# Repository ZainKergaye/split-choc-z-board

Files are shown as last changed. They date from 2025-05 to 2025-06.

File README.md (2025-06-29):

# Choc split-key z-board

The choc split key zboard is another ergonomic split-keyboard designed for comfort and efficiency. Using wired USB-C connectors to communicate between halves, it is a plain simple keyboard.

## Table of Contents

1. [Introduction](#introduction)
2. [Features](#features)
3. [Getting Started](#getting-started)
4. [Hardware](#hardware)
5. [Initial Board Testing](#initial-board-testing)
6. [Assembly](#assembly)
7. [Firmware Installation](#firmware-installation)
8. [Troubleshooting](#troubleshooting)

## Features

- Ergonomic split design for improved comfort
- Custom PCB with SMD and THC components
- Open-source firmware using [QMK](https://docs.qmk.fm).
- 3D printed [case](https://www.printables.com/@ZainKergaye_241410)

## Getting Started

To make your own keyboard order all the parts in the [hardware](#hardware) section. Solder
everything according to the silkscreen, be prepared to solder SMD and THC components. 3D
print the case. Build and flash the firmware. Then you are done!

## Hardware

### PCB

Order the PCB from any manufacurer you want, the exported gerbers are below.

[Left half gerbers](./split-choc-z-board/gerbers/left-half-gerbers.zip)

### Components

[Choc v1 switches](https://www.amazon.com/dp/B0BLC9BKW8)

[Keycaps](https://www.amazon.com/dp/B0D2DCDBSW)

[QSPI Flash](https://www.digikey.com/en/products/detail/winbond-electronics/W25Q128JVSIQ-TR/5803944)

[RP2040](https://www.digikey.com/en/products/detail/raspberry-pi/SC0914-13/14306010?s=N4IgTCBcDaIE4AcwAYAsyQF0C%2BQ)

[Button](https://www.digikey.com/en/products/detail/e-switch/TL3315NF250Q/1870396)

[Resistor 10k](https://www.digikey.com/en/products/detail/bourns-inc/CR0603-FX-1002ELF/3593188)

[Resistor 27.4k](https://www.digikey.com/en/products/detail/bourns-inc/CR0603-FX-27R4ELF/3783905)

[Resistor 4.99k](https://www.digikey.com/en/products/detail/bourns-inc/CR0603-FX-4991ELF/2345092)

[Resistor 1k](https://www.digikey.com/en/products/detail/bourns-inc/CR0603-JW-102ELF/3741004)

[Capacitor 15pf](https://www.digikey.com/en/products/detail/murata-electronics/GCM1555C1H150JA16D/4903554)

[Capacitor 10uf](https://www.digikey.com/en/products/detail/samsung-electro-mechanics/CL05A106MQ5NUNC/3887109)

[Capacitor 1uf](https://www.digikey.com/en/products/detail/taiyo-yuden/JMK105BJ105KV-F/930583)

[Capacitor 0.1uf](https://www.digikey.com/en/products/detail/samsung-electro-mechanics/CL05B104KP5NNNC/3886660)

[USB-C connector](https://www.digikey.com/en/products/detail/gct/USB4105-GF-A/11198441)

[Diodes](https://www.digikey.com/en/products/detail/mcc-micro-commercial-components/1N4148W-TP/717196)

[Electrostatic protection](https://www.digikey.com/en/products/detail/umw/usblc6-2sc6/16705896)

One USB-C data cable to communicate between halves and one more to communicate to the computer.

### Additional tools

- Hot air soldering station / Reflow oven
- Soldering iron
- Solder wire
- Solder paste (For SMD)
- Rosin

## Initial Board Testing

While assembling the board, it's very important to make sure the RP2040 works.
Solder the main chip along with the top USB-C connector, Power regulation, QSPI flash,
and all the other decoupling capacitors and resistors. Don't solder the lower USB-C or
it's ESD protection or any other keyswitches. GPIO 24 is exposed through the 2.7mm dupont holes.
Simply connect an led and 1k ohm resistor to it and upload blink.py. This will give you a basic
program that tells you if the whole chip works or not.

## Assembly

> [!NOTE]
> Currently a work in progress, more pictures will be coming.

Assembly will require you to have kicad board editor open while you populate the board
in order to know which component goes where. Definately not recommended as a first beginner project.

## Firmware Installation

See the [build environment setup](https://docs.qmk.fm/#/getting_started_build_tools) and the [make instructions](https://docs.qmk.fm/#/getting_started_make_guide) for more information.

After setting up your build environment, simply use this command to flash

```bash

make e88:default:flash

```

## Troubleshooting

If you have encountered any problems or issues, feel free to create an issue [here](https://github.com/ZainKergaye/split-choc-z-board/issues)!

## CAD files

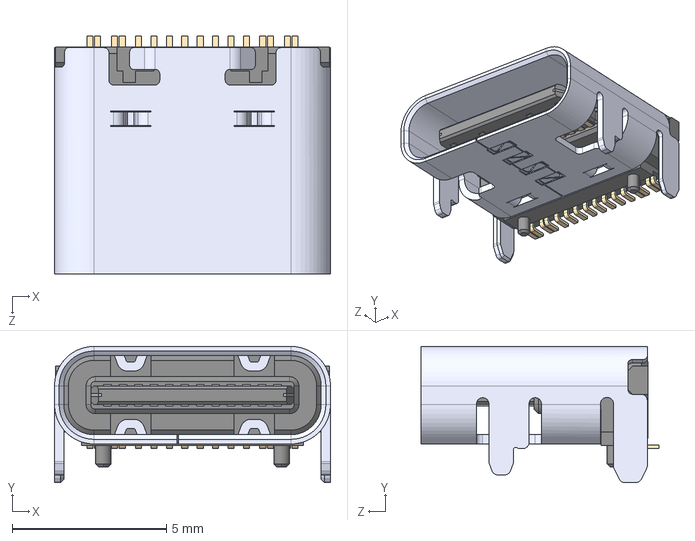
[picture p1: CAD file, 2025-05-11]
models/USB4105-GF-A/USB4105-GF-A.STEP
8.94 x 4.41 x 7.71 mm

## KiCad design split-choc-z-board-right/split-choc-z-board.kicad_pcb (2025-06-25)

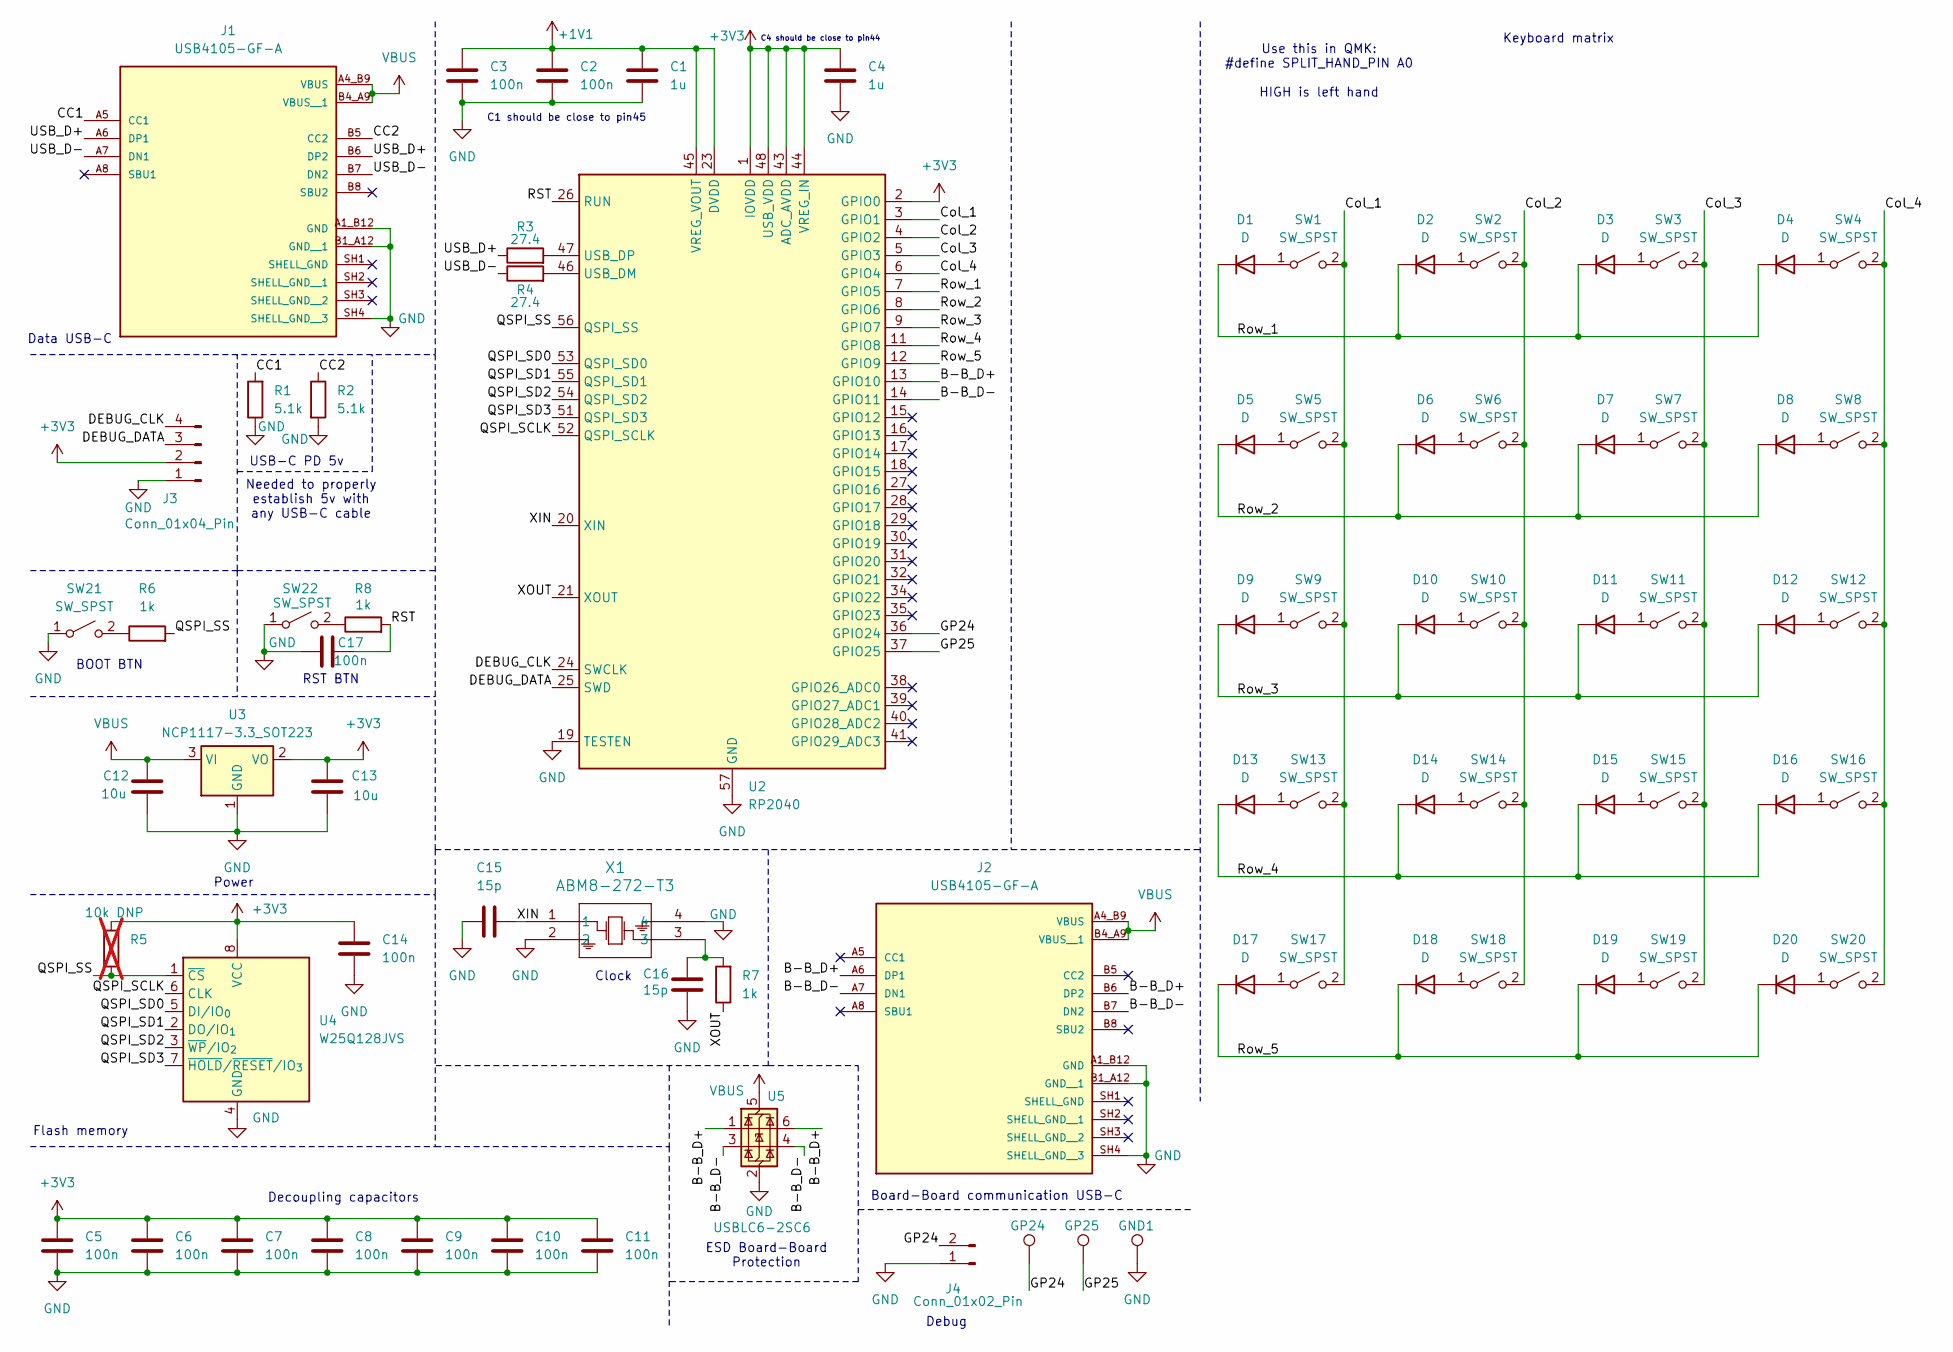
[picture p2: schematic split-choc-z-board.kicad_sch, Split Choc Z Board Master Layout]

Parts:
C1, C4: 1u; C_0402_1005Metric
C2, C3, C5, C6, C7, C8, C9, C10, C11, C14, C17: 100n; C_0402_1005Metric
C12, C13: 10u; C_0402_1005Metric
C15, C16: 15p; C_0402_1005Metric
D1, D2, D3, D4, D5, D6, D7, D8, D9, D10, D11, D12, D13, D14, D15, D16, D17, D18, D19, D20: D; SOD123_MCC
GND1: TestPoint; TestPoint_Pad_D2.0mm
GP24, GP25: TestPoint; TestPoint_Pad_D2.0mm
J1, J2: USB4105-GF-A; GCT_USB4105-GF-A; PARTREV B4
J3: Conn_01x04_Pin; PinHeader_1x04_P2.54mm_Vertical
J4: Conn_01x02_Pin; PinHeader_1x02_P2.54mm_Vertical
R1, R2: 5.1k; R_0603_1608Metric
R3, R4: 27.4; R_0603_1608Metric
R5: 10k DNP; R_0603_1608Metric; not fitted
R6, R7, R8: 1k; R_0603_1608Metric
SW1, SW2, SW3, SW4, SW5, SW6, SW7, SW8, SW9, SW10, SW11, SW12, SW13, SW14, SW15, SW16, SW17, SW18, SW19, SW20: SW_SPST; Choc_V1_1.00u
SW21, SW22: SW_SPST; SW_TL3315NF250Q
U2: RP2040; QFN-56-1EP_7x7mm_P0.4mm_EP3.2x3.2mm
U3: NCP1117-3.3_SOT223; SOT-223-3_TabPin2
U4: W25Q128JVS; SOIC-8_5.3x5.3mm_P1.27mm
U5: USBLC6-2SC6; SOT-23-6
X1: ABM8-272-T3; ABM8-272-T3_ABR

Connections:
+1V1: C1.1, C2.1, C3.1, U2.23 (DVDD), U2.45 (VREG_VOUT), U2.50 (DVDD)
+3V3: C4.1, C5.1, C6.1, C7.1, C8.1, C9.1, C10.1, C11.1, C13.1, C14.1, J3.2, R5.1, U2.1 (IOVDD), U2.2 (GPIO0), U2.10 (IOVDD), U2.22 (IOVDD), U2.33 (IOVDD), U2.42 (IOVDD), U2.43 (ADC_AVDD), U2.44 (VREG_IN), U2.48 (USB_VDD), U2.49 (IOVDD), U3.2 (VO), U4.8 (VCC)
/B-B_D+: J2.A6 (DP1), J2.B6 (DP2), U2.13 (GPIO10), U5.1 (I/O1), U5.6 (I/O1)
/B-B_D-: J2.A7 (DN1), J2.B7 (DN2), U2.14 (GPIO11), U5.3 (I/O2), U5.4 (I/O2)
/CC1: J1.A5 (CC1), R1.2
/CC2: J1.B5 (CC2), R2.1
/Col_1: SW1.2 (B), SW5.2 (B), SW9.2 (B), SW13.2 (B), SW17.2 (B), U2.3 (GPIO1)
/Col_2: SW2.2 (B), SW6.2 (B), SW10.2 (B), SW14.2 (B), SW18.2 (B), U2.4 (GPIO2)
/Col_3: SW3.2 (B), SW7.2 (B), SW11.2 (B), SW15.2 (B), SW19.2 (B), U2.5 (GPIO3)
/Col_4: SW4.2 (B), SW8.2 (B), SW12.2 (B), SW16.2 (B), SW20.2 (B), U2.6 (GPIO4)
/DEBUG_CLK: J3.4, U2.24 (SWCLK)
/DEBUG_DATA: J3.3, U2.25 (SWD)
/GP24: GP24.1, J4.2, U2.36 (GPIO24)
/GP25: GP25.1, U2.37 (GPIO25)
/QSPI_SCLK: U2.52 (QSPI_SCLK), U4.6 (CLK)
/QSPI_SD0: U2.53 (QSPI_SD0), U4.5 (DI/IO_{0})
/QSPI_SD1: U2.55 (QSPI_SD1), U4.2 (DO/IO_{1})
/QSPI_SD2: U2.54 (QSPI_SD2), U4.3 (~WP/IO_{2})
/QSPI_SD3: U2.51 (QSPI_SD3), U4.7 (~HOLD/~RESET/IO_{3})
/QSPI_SS: R5.2, R6.2, U2.56 (QSPI_SS), U4.1 (~CS)
/RST: C17.2, R8.2, U2.26 (RUN)
/Row_1: D1.1 (K), D2.1 (K), D3.1 (K), D4.1 (K), U2.7 (GPIO5)
/Row_2: D5.1 (K), D6.1 (K), D7.1 (K), D8.1 (K), U2.8 (GPIO6)
/Row_3: D9.1 (K), D10.1 (K), D11.1 (K), D12.1 (K), U2.9 (GPIO7)
/Row_4: D13.1 (K), D14.1 (K), D15.1 (K), D16.1 (K), U2.11 (GPIO8)
/Row_5: D17.1 (K), D18.1 (K), D19.1 (K), D20.1 (K), U2.12 (GPIO9)
/USB_D+: J1.A6 (DP1), J1.B6 (DP2), R3.1
/USB_D-: J1.A7 (DN1), J1.B7 (DN2), R4.1
/XIN: C15.2, U2.20 (XIN), X1.1
/XOUT: R7.1, U2.21 (XOUT)
GND: C1.2, C2.2, C3.2, C4.2, C5.2, C6.2, C7.2, C8.2, C9.2, C10.2, C11.2, C12.2, C13.2, C14.2, C15.1, C16.2, C17.1, GND1.1, J1.A1_B12 (GND), J1.B1_A12 (GND__1), J1.SH4 (SHELL_GND__3), J2.A1_B12 (GND), J2.B1_A12 (GND__1), J2.SH4 (SHELL_GND__3), J3.1, J4.1, R1.1, R2.2, SW21.1 (A), SW22.1 (A), U2.19 (TESTEN), U2.57 (GND), U3.1 (GND), U4.4 (GND), U5.2 (GND), X1.2, X1.4
unnamed: C16.1, R7.2, X1.3
unnamed: D1.2 (A), SW1.1 (A)
unnamed: D2.2 (A), SW2.1 (A)
unnamed: D3.2 (A), SW3.1 (A)
unnamed: D4.2 (A), SW4.1 (A)
unnamed: D5.2 (A), SW5.1 (A)
unnamed: D6.2 (A), SW6.1 (A)
unnamed: D7.2 (A), SW7.1 (A)
unnamed: D8.2 (A), SW8.1 (A)
unnamed: D9.2 (A), SW9.1 (A)
unnamed: D10.2 (A), SW10.1 (A)
unnamed: D11.2 (A), SW11.1 (A)
unnamed: D12.2 (A), SW12.1 (A)
unnamed: D13.2 (A), SW13.1 (A)
unnamed: D14.2 (A), SW14.1 (A)
unnamed: D15.2 (A), SW15.1 (A)
unnamed: D16.2 (A), SW16.1 (A)
unnamed: D17.2 (A), SW17.1 (A)
unnamed: D18.2 (A), SW18.1 (A)
unnamed: D19.2 (A), SW19.1 (A)
unnamed: D20.2 (A), SW20.1 (A)
unnamed: R6.1, SW21.2 (B)
unnamed: R8.1, SW22.2 (B)
unnamed: R4.2, U2.46 (USB_DM)
unnamed: R3.2, U2.47 (USB_DP)
VBUS: C12.1, J1.A4_B9 (VBUS), J1.B4_A9 (VBUS__1), J2.A4_B9 (VBUS), J2.B4_A9 (VBUS__1), U3.3 (VI), U5.5 (VBUS)

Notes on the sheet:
BOOT BTN
Use this in QMK: #define SPLIT_HAND_PIN A0 HIGH is left hand
Clock
RST BTN
Flash memory
C1 should be close to pin45
Debug
Data USB-C
Board-Board communication USB-C
Keyboard matrix
C4 should be close to pin44
USB-C PD 5v
Decoupling capacitors
Power
ESD Board-Board Protection
Needed to properly establish 5v with any USB-C cable

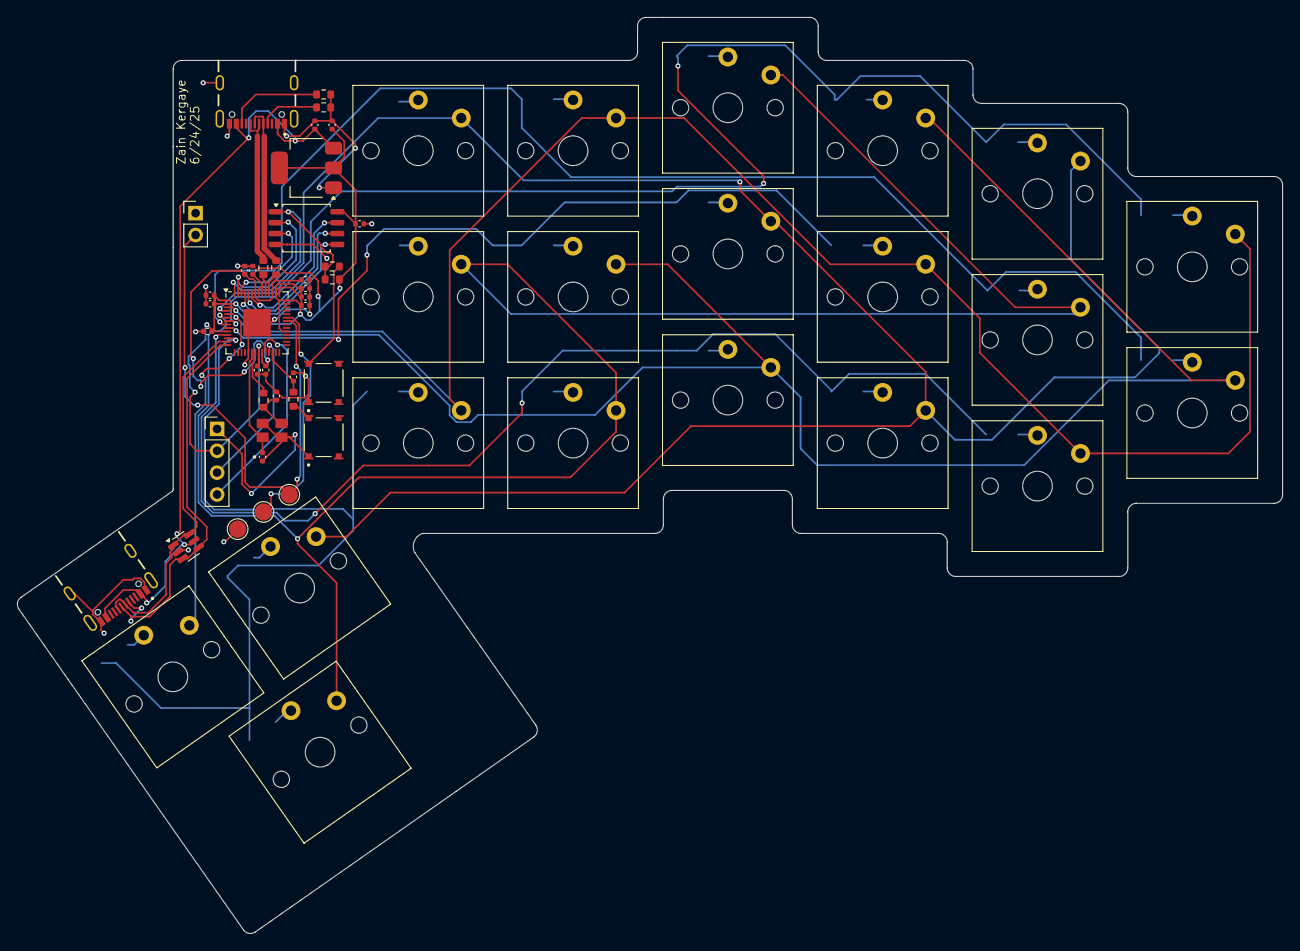
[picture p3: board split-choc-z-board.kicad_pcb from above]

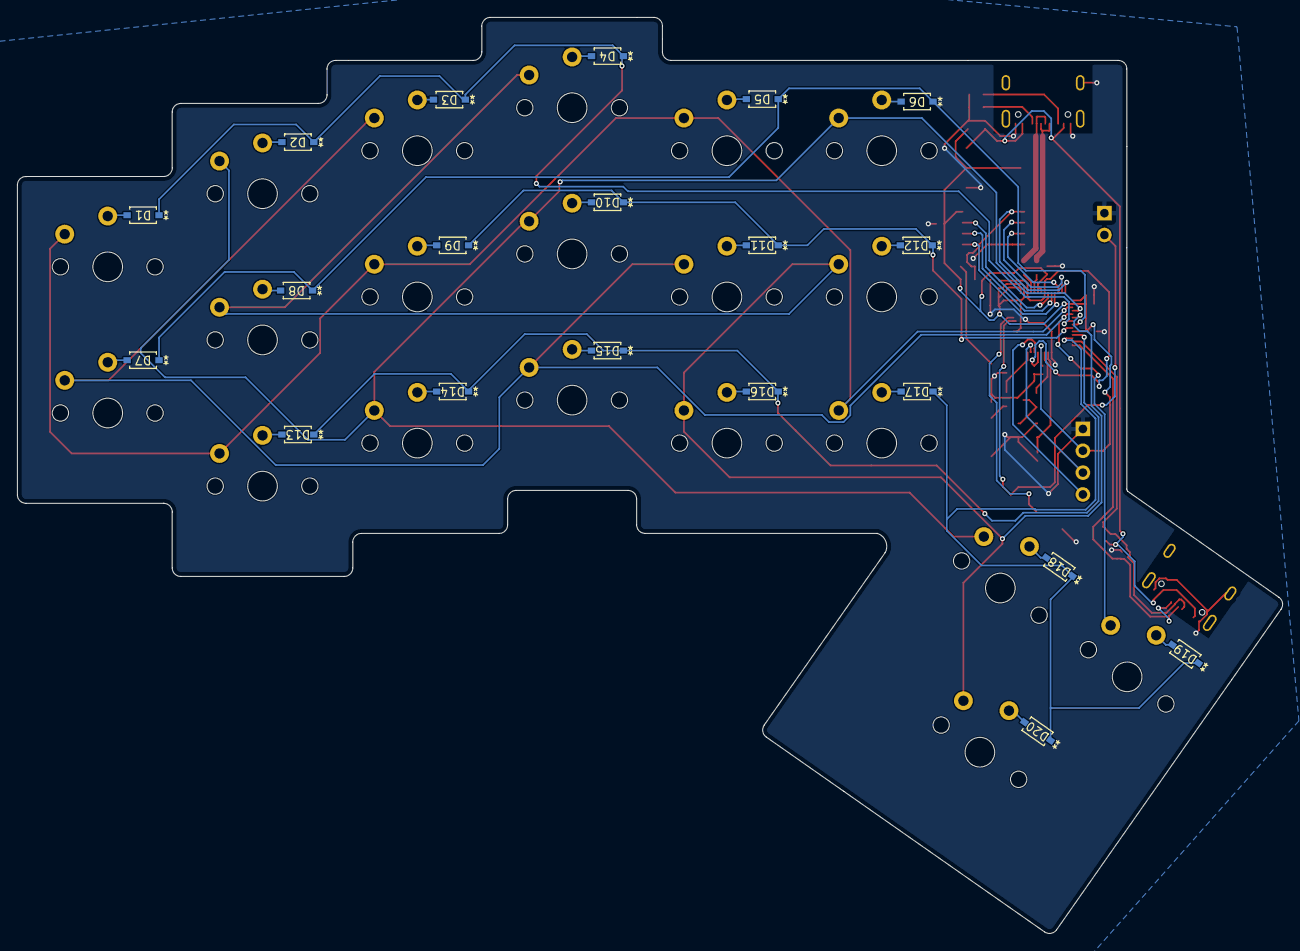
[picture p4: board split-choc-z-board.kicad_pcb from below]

Board: 2 copper layers, 147.1 x 106.5 mm, 79 parts (20 on the bottom side), 57 nets.

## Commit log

2025-05-07 Finished basic layout and just started making split board from main sch
    [split-choc-z-board-left.kicad_sch, split-choc-z-board-right.kicad_sch, split-choc-z-board.kicad_pcb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]
2025-05-08 Refactored schematic and added footprint library
    [left-side.kicad_sch, split-choc-z-board-left.kicad_sch, split-choc-z-board-right.kicad_sch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]
2025-05-08 Added more footprints to symbols and started placement
    [split-choc-z-board.kicad_pcb, split-choc-z-board.kicad_sch]
2025-05-09 Changed TTRS to USB C
    [split-choc-z-board.kicad_pcb, split-choc-z-board.kicad_sch]
2025-05-11 Update: Defined components in README and added ESD protection. Also changed USBC connector
    [split-choc-z-board.kicad_sch]
2025-05-11 Update: Added more footprints 🚀
    [USB4105-GF-A.STEP, USB4105-GF-A.step, split-choc-z-board.kicad_pcb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]
2025-05-11 Adding more to pcb
    [split-choc-z-board.kicad_pcb]
2025-05-12 Finalized placement of components 🎉 and defined edge
    [split-choc-z-board.kicad_pcb]
2025-05-12 Fixed edgecut DRC. Ready for routing!
    [split-choc-z-board.kicad_pcb]
2025-05-12 Added right half! Flipped PCB, tx and rx on USBC, and handness pin
    [split-choc-z-board.kicad_pcb, split-choc-z-board.kicad_sch]
2025-05-12 Finished routing right side! 🤖
    [split-choc-z-board.kicad_pcb, split-choc-z-board.kicad_sch]
2025-05-12 Routed left side! 😃
    [split-choc-z-board.kicad_pcb]
2025-05-12 Added text on silkscreen
    [split-choc-z-board.kicad_pcb]
2025-05-12 Update: Exported gerbers!
    [split-choc-z-board.kicad_pcb]
2025-05-14 Not sure what changed here
    [split-choc-z-board.kicad_pcb]
2025-05-18 Updated README! 🙋
2025-05-18 Adding more docs 📘
2025-06-14 Removed right side, need to redo MCU 😢
    [split-choc-z-board.kicad_pcb, split-choc-z-board.kicad_sch]
2025-06-15 Added kb library for 128x32 oled display and deleted MCU 🥳
    [split-choc-z-board.kicad_sch]
2025-06-16 Added RP2040! 😅 Hopefully no errors to come
    [split-choc-z-board.kicad_sch]
2025-06-17 Added debug pads
    [split-choc-z-board.kicad_pcb, split-choc-z-board.kicad_sch]
2025-06-17 Updated README 📕
2025-06-18 Placed all components properly! 😄
    [split-choc-z-board.kicad_pcb, split-choc-z-board.kicad_sch]
2025-06-18 Finished board outline 🖥️
    [split-choc-z-board.kicad_pcb]
2025-06-18 Moved switch layout around and changed constraints for JLCPCB ⚡
    [split-choc-z-board.kicad_pcb]
2025-06-18 Copied project for right side
    [left-side.kicad_sch, split-choc-z-board-left.kicad_sch, split-choc-z-board.kicad_pcb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]
2025-06-18 Finalized component placement! 💡
    [split-choc-z-board.kicad_pcb]
2025-06-19 Almost done routing left side
    [split-choc-z-board.kicad_pcb]
2025-06-20 Almost finished left half routing
    [split-choc-z-board.kicad_pcb]
2025-06-20 Routed left side
    [split-choc-z-board.kicad_pcb, split-choc-z-board.kicad_sch]
2025-06-21 Finished routing USB and added easier to use debug connectors
    [split-choc-z-board.kicad_pcb, split-choc-z-board.kicad_sch]
2025-06-21 Updated right side schematic to match left
    [split-choc-z-board.kicad_sch]
2025-06-22 Copied left hand component placement changes to right hand
    [split-choc-z-board.kicad_pcb]
2025-06-23 Routing right side!
    [split-choc-z-board.kicad_pcb]
2025-06-23 Finished routing right! 👏🏻
    [split-choc-z-board.kicad_pcb]
2025-06-24 Finished cleaning up left side! 🥳
    [split-choc-z-board.kicad_pcb]
2025-06-24 Finished up right half! 🎉
    [split-choc-z-board.kicad_pcb]
2025-06-24 Added gerbers
    [split-choc-z-board.kicad_pcb]
2025-06-25 Added name and date to board
2025-06-25 Added name and date to board 2
    [split-choc-z-board.kicad_pcb]
2025-06-26 Updating submodule 📕
2025-06-29 Added more to README! 🥸
